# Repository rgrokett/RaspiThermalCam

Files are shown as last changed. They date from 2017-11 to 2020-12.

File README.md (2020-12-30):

# PiEyeR RaspiThermalCam
## Portable Raspberry Pi AMG8833 Grid-Eye IR Thermal Camera

version 0.8.2 - 2017-12-03

### Overview
The Adafruit AMG8833 IR Thermal Camera board can provide a “FLIR™”-like imaging camera at about 1/10th the price of previous IR Thermal imaging units.  Of course, the resolution and sensitivity are not as high as more advanced cameras, but hey, for $39 it’s a great deal.  

Note that IR Thermal Cameras are NOT the same as NOIR cameras. The former uses only the heat given off by the object being imaged, while the latter requires an infrared light source such as IR LEDs to illuminate the object. 

With this project, I took the excellent Adafruit tutorial [Raspberry Pi Thermal Camera](https://learn.adafruit.com/adafruit-amg8833-8x8-thermal-camera-sensor/raspberry-pi-thermal-camera) by Dean Miller and added extra functionality to the software and hardware.

The PiTFT display uses Adafruit's custom Linux Kernel. *(See below)* This project only needs the Jessie Lite-based PiTFT Resitive Image, as it does not use the GUI.

### New features:
- Safely shutdown/power up Raspberry
- Automatically runs software at powerup
- Battery Powered for portability
- Uses PiTFT GPIO buttons
- Sensitivity controls
- Screen snapshots
- Potential for future additions

**See Full Instructions in the [RaspiThermalCam.pdf](https://github.com/rgrokett/RaspiThermalCam/raw/master/RaspiThermalCam.pdf) document**

Zero Owners:  A Raspberry Pi Zero can be used instead of a Pi 3, sacrificing speed. See the subdirectory RaspiThermalCam/Zero for details.

### Requirements (summary)
**NOTE:** This project assumes the user has set up their Raspberry Pi using the Adafruit tutorial mentioned above, thus consists of:
1. [Raspberry Pi Thermal Camera](https://learn.adafruit.com/adafruit-amg8833-8x8-thermal-camera-sensor/raspberry-pi-thermal-camera) 
- Adafruit AMG8833 IR Thermal Camera Breakout [ID 3538](https://www.adafruit.com/product/3538)
2. It also specifically requires the Adafruit PiTFT Plus 2.8" 320x240 screen to be installed and running. 
- [Required PiTFT Kernal Install](https://learn.adafruit.com/adafruit-pitft-28-inch-resistive-touchscreen-display-raspberry-pi/easy-install)
- Download [Jessie Lite-based PiTFT image ](https://s3.amazonaws.com/adafruit-raspberry-pi/2016-10-18-pitft-28r-lite.zip)
- PiTFT Plus 2.8" TFT 320x240 Touch Screen [ID 2298](https://www.adafruit.com/product/2298)
3. Currently uses also:
- Raspberry Pi 3, 4GB or larger micro SD card
- 5V power supply, wiring, cables, etc.
4. It DOES NOT require the Cobbler as mentioned, but does need a cable to connect the camera. I suggest:
- Adafruit 40 Pin GPIO Cable [ID 1988](https://www.adafruit.com/product/1988)
- Adafruit 2X20 Pin IDC Box Header [ID 1993](https://www.adafruit.com/product/1993)

### Extras
- Faceplate and case for PiTFT and Raspberry Pi 3 [ID 2807](https://www.adafruit.com/product/2807)
- 5V external USB Battery (such as external cellphone rechargeable) with 2 amp output
- Box to hold battery, computer and camera 

### Installation
#### Pre Raspbian Buster:
You **MUST** have the Adafruit tutorial version installed and working before using this. This project just replaces the Adafruit thermalcam.py with a new python program. IT WILL NOT WORK OTHERWISE.

Also, it expects the assembled version of the Adafruit 2.8" 320x240 PiTFT Plus screen otherwise the screen layout will NOT ALIGN and the GPIO buttons will NOT FUNCTION as expected. The Raspbian GUI is NOT NEEDED, so uses their custom Jessie Lite. 

The camera should be facing forward, like a digital camera: LCD screen towards you and camera towards (hot) object. 

1. Log into the Raspberry Pi with SSH or keyboard (defaults to "pi/raspberry")
2. Download and install the enhanced thermal program:
```
git clone https://github.com/rgrokett/RaspiThermalCam.git
cd RaspiThermalCam
./install.sh
sudo reboot
```

#### Raspbian Buster Lite:
Wire up the thermal camera sensor and the PiTFT as outlined in the PDF in this repository. Make the necessary changes to raspi-config as outlined in the same PDF.

1. Log into the Raspberry Pi with SSH or keyboard (defaults to "pi/raspberry")
2. Download and install the enhanced thermal program:
```
git clone https://github.com/tenbergen/RaspiThermalCam.git
cd RaspiThermalCam
chmod +x ./buster-install.sh
./buster-install.sh
```
This will install the PiTFT and thermal sensor driver, if necessary. During PiTFT driver installation, select "4" for 2.8" capacitive PiTFT, then select "1" for 90 degree rotation, then select "no" for console on screen, then select "yes" for mirror HDMI output. Finally, select "no" to reboot.

The installer script will continue with the RaspiThermalCam installation. When complete, type:

```
sudo reboot
```

#### Overlay Kiosk:
In raspi-config, activate camera. Then, install using buster-install.sh.
Afterwards, type:
```
sudo pip3 install picamera
contab -e
```
and edit crontab to remove old script, and instead point to raspithermalcamoverlaykiosk.sh.

#### After Installation:
Once rebooted, you should see the new PiEyeR screen. See Troubleshooting if needed.  

The 4 buttons on the TFT screen have been re-mapped to GPIO functions as shown:

1. Safely Shutdown/Start up Raspberry (Does not remove 5V power, must be done usually via the 5V USB battery on/off switch)
2. Increase Sensitivity (while in Camera Mode)
3. Decrease Sensitivity (while in Camera Mode)
4. Start/Stop Camera Mode

### Snapshot
Due to a bug in the Python SDL library, the touch screen doesn’t currently work with PyGame software.  So I used the tslib and a small custom C program to detect screen touches.

Unfortunately, this broke in Raspbian Buster. Otherwise, to take a screenshot of a thermal image, just touch anywhere on the touch screen.  The screen will flash to let you know an image has been taken.
Images are saved to the /home/pi/snapshot subdirectory as  PNG files. These can be transferred to your PC using:

Mac/Linux:
$ scp pi@YOUR_IP_ADDRESS :/home/pi/snapshot/*.png .

Windows:
Use WinSCP program https://winscp.net/eng/download.php
Connect using SFTP with user name pi and Host name YOUR_IP_ADDRESS
Navigate to snapshot folder and select and download to your PC.

### 3D Print Case (early version)
The stl/ subdirectory contains 3D Printed front case parts for the camera. See the PDF document for details.

### Future 
- Switch to using Raspberry Pi Zero W for lower cost & power/smaller size
- Add new mode button features for middle buttons
- Get pygame Touch Screen working for PiTFT

### Troubleshooting

**I don't see any new screen, only the boot messages and login.** 

Did you run the ./install.sh script? 
Try running $ crontab -l and see if you see a @reboot line:
```
@reboot sudo python /home/pi/RaspiThermalCam/raspitherm.py >/dev/null 2>&1
``` 
You did set up your Pi Thermal Camera as detailed in the [Adafruit tutorial](https://learn.adafruit.com/adafruit-amg8833-8x8-thermal-camera-sensor/raspberry-pi-thermal-camera) 

**I get a python error message**
Most likely there is a missing python package. The last line of the Python error should say what is missing. Try Googling that message.
Else, leave an Issue here at Github.

**My screen is mangled up, but the buttons seem to work**
Are you using the PiTFT Plus 2.8" 320x240 screen?  

**My buttons don't work or are on the bottom not side of the PiTFT**
You have a different screen. If you have GPIO buttons on botton of TFT, you can try remapping them in the raspitherm.py program.

**The Touchscreen doesn't work**
Bugs in the SDL software used by pygame make for inconsistent operation of the touch screen. We have to wait for a better solution. This program doesn't use the touch, just buttons.

**My Camera screen is all BLUE or all RED**
Press the Sensitivity buttons (middle two) to increase/decrease sensitivity

**My Camera doesn't work**
Try manually running tools/thermal_cam.py program. This is the same program from Adafruit with no modifications.
You may need to kill the raspitherm.py program first by editing the crontab:
```
crontab -e
comment out the @reboot line
#@reboot ...
```
**What can I see with it?**
Find a cat. They glow hot!
So do water heaters!

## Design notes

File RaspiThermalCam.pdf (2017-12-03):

### PiEyeR – Enhanced Thermal Camera for Raspberry Pi

v. 2017-12-03 r.grokett

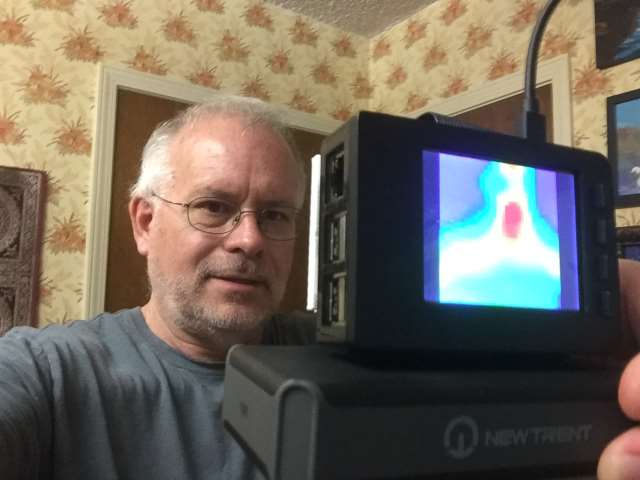
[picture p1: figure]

### Overview

The Adafruit AMG8833 IR Thermal Camera board can provide a “FLIR™”-like imaging camera at about 1/10th the price of previous IR Thermal imaging units. Of course, the resolution and sensitivity are not as high as more advanced cameras, but hey, for $39 it’s a great deal.

Note that IR Thermal Cameras are NOT the same as NOIR cameras. The former uses only the heat given off by the object being imaged, while the latter requires an infrared light source such as IR LEDs to illuminate the object.

With this project, I took the excellent Adafruit tutorial “Raspberry Pi Thermal Camera” by Dean Miller and added extra functionality to the software and hardware.

The PiTFT display uses Adafruit's custom Linux Kernel. (See below) This project only needs the Jessie Lite-based PiTFT Resistive Image, as it does not use the GUI.

New Features:

- Safely shutdown/power up Raspberry
- Automatically runs software at powerup
- Battery Powered for portability
- Uses PiTFT GPIO buttons
- Sensitivity controls
- Full screen thermal display
- Screen snapshots
- 3D printed case
- Potential for future additions

Hardware

- Raspberry Pi 3 (best) or Raspberry Pi W.
- Adafruit AMG8833 IR Thermal Camera Breakout https://www.adafruit.com/product/3538
- PiTFT Plus Assembled 320x240 2.8" TFT + Resistive Touchscreen https://www.adafruit.com/product/2298
- Faceplate and case for piTFT and RaspberryPi 3 https://www.adafruit.com/product/2807https://www.adafruit.com/product/2253
- Adafruit 40 Pin GPIO Cable https://www.adafruit.com/product/1988
- Adafruit 2X20 Pin IDC Box Header https://www.adafruit.com/product/1993
- 5V USB Battery (such as external cellphone rechargeable) 3000mah or larger
- 4GB or larger micro SD card for Raspberry
- Wire, connectors, etc. to match your connections
•

Software

- Custom Raspbian Jessie Lite for PiTFT (described below)
- Adafruit Libraries for PiTFT and AMG8833 (described below)
- SSH & Putty for Windows
- RaspiThermalCam from Github https://github.com/rgrokett/RaspiThermalCam

### I. Preliminary Setup

If you already have set up a Raspberry Pi with an Adafruit PiTFT Plus 320x240 screen and AMG8833 Thermal Camera module, then you can skip to the RaspiThermalCam Software in section II. below.

### Install PiTFT Display

Because the PiTFT Resistive Touch screen requires modifications to the Raspbian kernel, it is STRONGLY suggested to start fresh with the custom pre-built Raspbian Jessie image from Adafruit. This already contains all the necessary drivers for the PiTFT screen.

Note that this is going to be a “headless” installation, thus will not be using the Raspbian GUI. You will be using the linux command-line to configure and program the Raspberry. The easiest way to access is to set up SSH and WiFi or Ethernet connectivity and use a remote terminal program like Putty.

The below instructions are taken from Adafruit PiTFT tutorial at the URL below. NOTE that if you have difficulties or want to see the full instructions please visit this site: https://learn.adafruit.com/adafruit-pitft-28-inch-resistive-touchscreen-display-raspberry-pi/easy-install

PiTFT Installation Steps

1) Download the piTFT Raspian Jessie Lite from Adafruit to a PC: https://s3.amazonaws.com/adafruit-raspberry-pi/2016-10-18-pitft-28r-lite.zip
2) Install this image on a 4GB or larger SD card. If you need help here, check out instructions at https://www.raspberrypi.org/documentation/installation/installing-images/
3) Insert the micro SD card into the Pi.
4) Before installing the piTFT onto the Pi, plug the 40 pin GPIO Cable into the back of the piTFT. BE SURE to position the GRAY line mark on the cable on PIN 1 of the piTFT male connector. Note that there are two connectors on the PiTFT module; a female connector that plugs into the Raspberry Pi, and a male connector that this cable connects to.

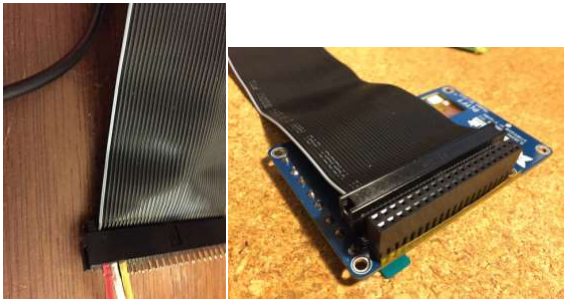
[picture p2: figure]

This will be used to connect the Thermal Camera module later.
(Actually, you only need 4 wires to connect the camera, but due to dimensions, it’s easiest to just use this ready-made cable as is.)
5) Now plug in the PiTFT onto the Raspberry Pi itself. Again, look at the photos to see which way it should go. (gray to pin 1)
6) Verify that the GRAY line mark on the GPIO cable is positioned as shown.

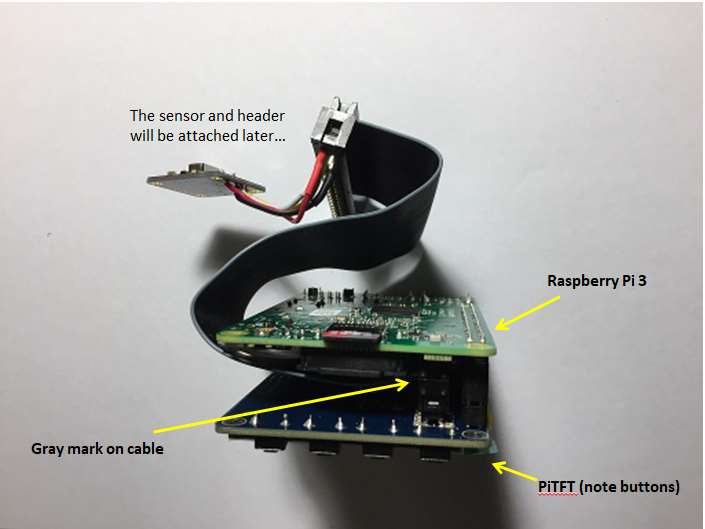
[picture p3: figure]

Now you are ready to test the PiTFT and Raspberry Pi. (The IR Image Sensor will be installed later).

7) Connect a USB keyboard into one of the Raspi ports. (No mouse is needed). This will make it easier to initially log in and find the IP address that is assigned. Otherwise, you’ll need to check your router for the IP assignment.
8) For network connectivity, the easiest is just plug in an Ethernet cable, though you can set up WiFi manually via wpa_supplicant.conf if you prefer.

Note that once the IR camera is completed, you won’t need networking, so wifi isn’t needed.

9) Connect 5V power and let your pi boot. If all goes well, after a few seconds, the PiTFT screen should show boot messages and then a login prompt.

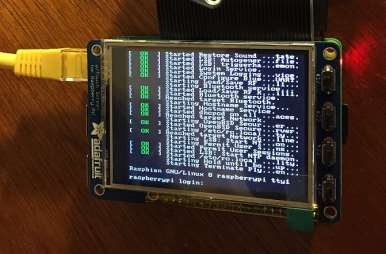
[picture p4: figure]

If you do not see any display, verify your connection (bent pins?), power supply and SD card are all good. Also see the Adafruit FAQ: https://learn.adafruit.com/adafruit-pitft-28-inch-resistive-touchscreen-display-raspberrypi/help-faq (https://learn.adafruit.com/adafruit-pitft-28-inch-resistive-touchscreen-display-raspberry-pi/help-faq)

10) Login & passwd are the default “pi” “raspberry”.
11) Locate the IP address using $ ifconfig –a
Now you can remotely log in using SSH Putty using pi@YOUR_IP_ADDRESS
You can unplug the keyboard once you successfully ssh in.
(Remote access is only needed just to make it easier to complete the setup, not for normal use.)
12) Update your package manager:

sudo apt-get update

IMPORTANT NOTE! Do NOT run “apt-get upgrade” or “rpi-update”!
This would overwrite the custom Adafruit kernel needed to run the PiTFT. If you do, probably easiest is to just start over. Or consult the Adafruit FAQ above.
This Pi will not be accessible from the Internet, so security patches aren’t as critical.
(If paranoid, just turn off WiFi and only use Ethernet cable.)

### AMG8833 Image Sensor Setup

The following is excerpted instructions from Adafruit’s Thermal Camera tutorial. Feel free to examine it for more details:
https://learn.adafruit.com/adafruit-amg8833-8x8-thermal-camera-sensor/raspberry-pi-thermal-camera
1) Run the following to install the Raspberry Library and Adafruit GPIO

sudo apt-get install -y build-essential python-pip python-dev python-smbus git git clone https://github.com/adafruit/Adafruit_Python_GPIO.git

cd Adafruit_Python_GPIO

sudo python setup.py install

sudo apt-get install -y python-scipy python-pygame

sudo pip install colour Adafruit_AMG88xx

This installs all the packages and libraries needed to drive the IR Image Sensor.

2) Enable the I2C Interface for the IP camera:

sudo raspi-config

Navigate to 9 Advanced Options and select A7 I2C then select Finish

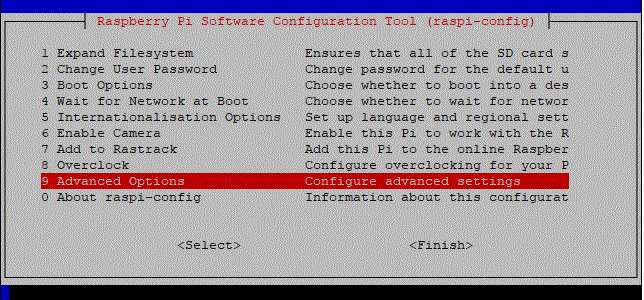
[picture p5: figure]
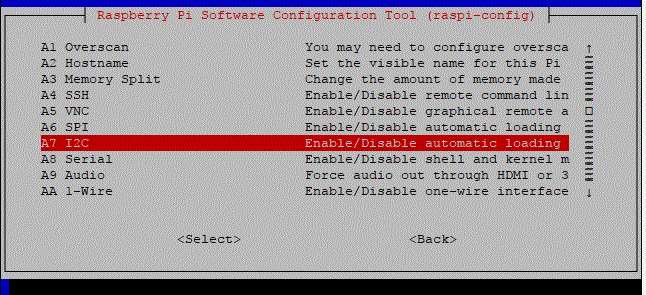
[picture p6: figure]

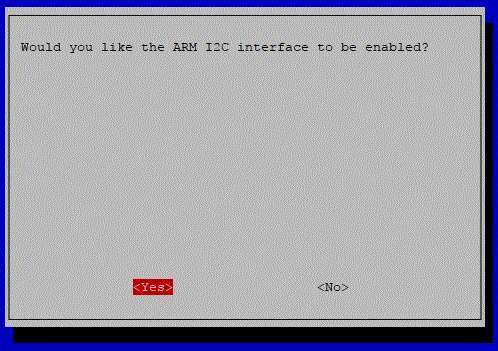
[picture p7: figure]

3) Shutdown Raspi and unplug the power cable (and Ethernet cable, if connected):

sudo shutdown -h now

Wiring the IR Module

You will be connecting only 4 pins of the AMG8833 IP to the 2x20 IDC Box Header and plugging this into the 40 wire GPIO cable.

For the most reliable wiring connectivity, I suggest soldering 4 short wires to the pins on the IR module and to the 2x20 Header. Use a needle point soldering iron and magnifier for best results. Use heat shrink tubing to protect the connections.

Be sure to note the direction positioning of the Header. There is a cutout key and a tiny arrow marking pin 1. (This is inverted from GPIO diagrams due to the cable/header arrangement)

Also note the direction that the IR camera should be pointing away from the Raspi.

IR MODULE | RASPBERRY PI (2x20 Box Header) | DESC
VIN | Pin 1 | 3.3V
GND | Pin 6 | Ground
SDA | Pin 3 | SDA
SCL | Pin 5 | SCL

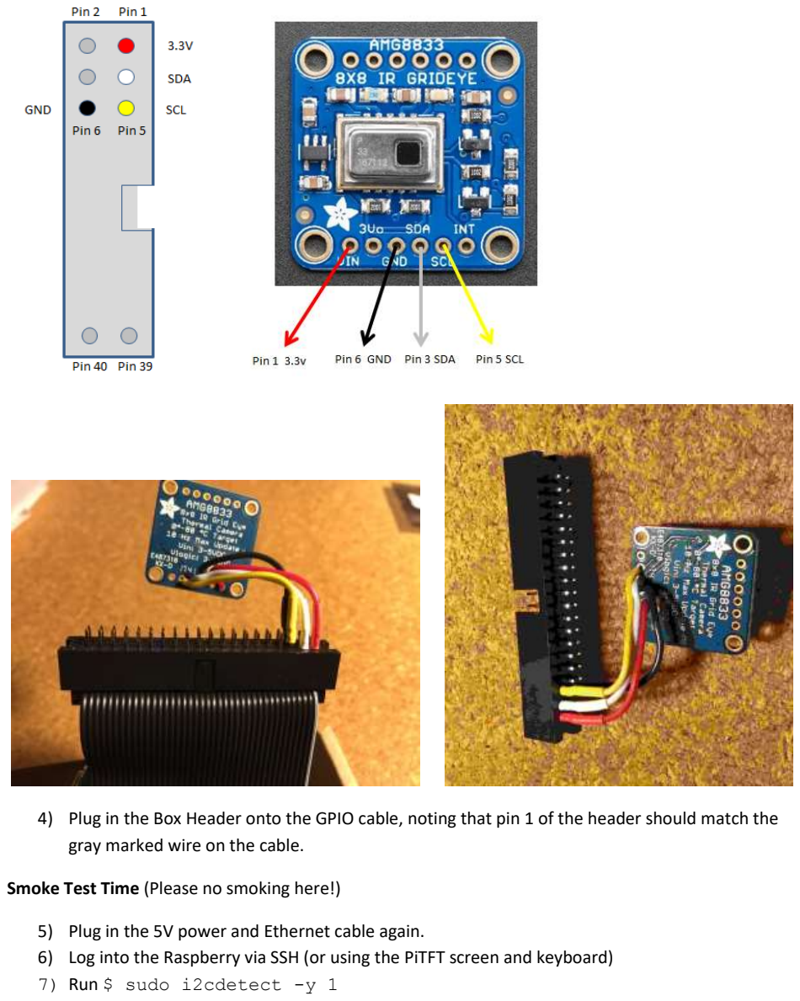
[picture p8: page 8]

4) Plug in the Box Header onto the GPIO cable, noting that pin 1 of the header should match the gray marked wire on the cable.

Smoke Test Time (Please no smoking here!)

5) Plug in the 5V power and Ethernet cable again.
6) Log into the Raspberry via SSH (or using the PiTFT screen and keyboard)
7) Run $ sudo i2cdetect -y 1

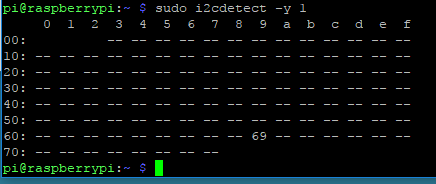
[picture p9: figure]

You should see the “69” entry. If not, did you enable the I2C interface via raspi-config? Also verify wiring!

8) Run the Example code!

cd ~/

git clone https://github.com/adafruit/Adafruit_AMG88xx_python.git

cd Adafruit_AMG88xx_python/examples

sudo python thermal_cam.py

If all is well, you should see a heat map image when you wave your hand or stand in front of the camera!

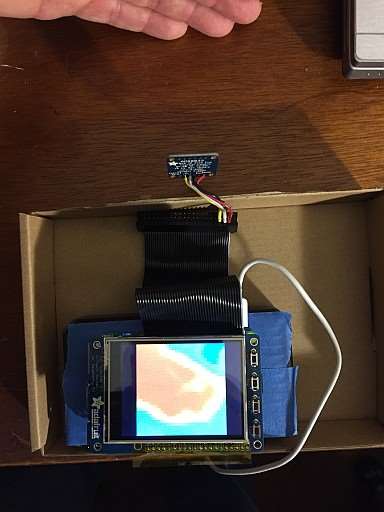
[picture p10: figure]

Once completed, the camera should be facing forward, like a digital camera: The LCD screen towards you and camera towards (hot) object.

### II. RaspiThermalCam Software

Now that you have a working Raspberry Pi Thermal Camera, the next step is to add extra software functionality and package everything into a more portable unit.

Before beginning, I suggest changing the password and setting the timezone.

$ sudo raspi-config

Select “Change User Password” and change as directed.
Then select “Internationalization Options” -> “Change TimeZone” and find a country/city in your timezone. Type first letter A-Z or page up/down to skip cities quickly.

Now to install the PiEyeR RaspiThermal software:

1) Install GIT, if needed:
| $ sudo apt-get install git
2) Download the RaspiThermalCam software
| $ cd ~/ $ git clone https://github.com/rgrokett/RaspiThermalCam.git
3) Run the Installation script
| $ cd RaspiThermalCam $ ./install.sh $ sudo reboot

Once rebooted, you should see the new PiEyeR screen.

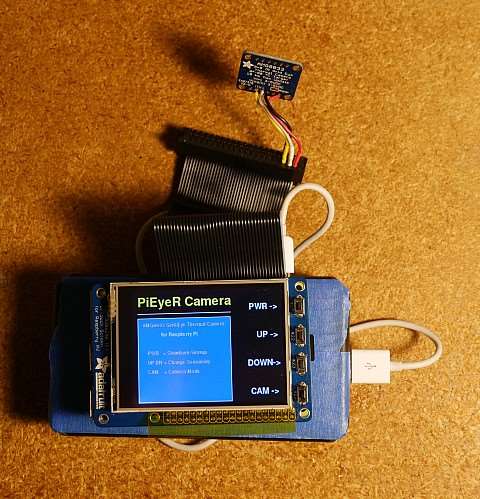
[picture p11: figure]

See Troubleshooting if needed.

The 4 buttons on the TFT screen have been re-mapped to GPIO functions as shown:

Button | GPIO | Desc
1 | 17 | Safely Shutdown/Start up Raspberry (Does not remove 5V power, must be done usually via the 5V USB battery on/off switch)
2 | 22 | Increase Sensitivity (while in Camera Mode)
3 | 23 | Decrease Sensitivity (while in Camera Mode)
4 | 27 | Start/Stop Camera Mode
(If needed, you can remap the buttons to your TFT screen’s GPIO pins by editing the "raspitherm.py" program.)

### Screenshots

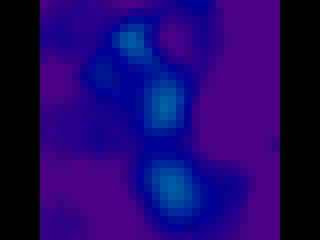
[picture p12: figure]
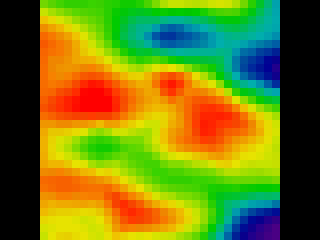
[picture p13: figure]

Due to a bug in the Python SDL library, the touch screen doesn’t currently work correctly with PyGame software. So I used the tslib and a small custom C program to detect screen touches.

To take a screenshot of a thermal image, just touch anywhere on the touch screen. The screen will flash to let you know an image has been taken.

Images are saved to the /home/pi/snapshot subdirectory as PNG files. These can be transferred to your PC using:

Mac/Linux:

$ scp –p pi@YOUR_IP_ADDRESS :/home/pi/snapshot/*.png .

Windows:
Use WinSCP program https://winscp.net/eng/download.php
Connect using SFTP with user name pi and Host name YOUR_IP_ADDRESS Navigate to snapshot folder and select and download to your PC.

### Packaging Construction

If you are going to use this outside, you should ruggedize it by soldering all wiring (or verify strong connections) and building a case. I used a simple 3D printed case I designed.

This also will use the Adafruit front faceplate, buttons and case for the Raspberry.

You will also need a large 5V USB battery to power the Pi 3, which I just attached separately using Velcro.

### 3D Printed Case

The RaspiThermalCam/stl/ subdirectory contains STL files for 3D printing a simple front-end case for the thermal sensor. It’s currently not very fancy and expects the Raspberry Pi 3 and PiTFT screen to use the Adafruit faceplate and case.

1. Print out the three pieces; body, front plate, back bracket.
2. Clip out the support tips along one edge of the wide end of the Body. This is where the ribbon cable will go thru.
3. Slip the Body over the AMG8833 camera module and cables, wide end towards the Raspberry Pi case.
4. Pull the camera module up through the front (narrower) end of the Body.
5. Place the camera through the hole in the front plate. Note that the ridge on the front plate faces OUTWARDS, thus helps protect the imager.
6. Place the bracket behind the camera module circuit board. The camera should be just lightly held in place by the bracket
7. Use two small screws/nuts to attach the bracket to the front plate with the camera sandwiched between.
8. Currently, I just glued the front plate to the Body. The camera can still be removed from the case by removing the screws and back bracket.
9. I also just attached the wide end of the Body to the Raspberry Pi case using hot melt glue, which can be cut or melted to open it back up.

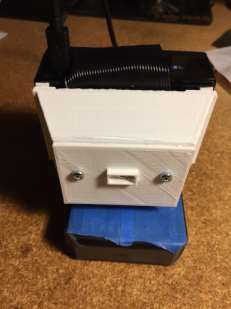
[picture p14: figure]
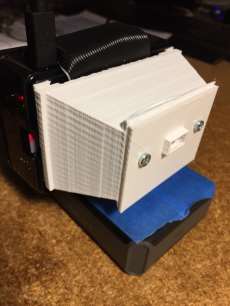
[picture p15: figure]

NOTE that you cannot cover the front lens of the AMG8833 as most glass or clear plastics will absorb the far-infrared, thus be opaque to the camera.

Since my next version of the PiEyeR is to try to replace the Raspberry Pi 3 with a Zero W, all of the case designs will change.

Feel free to design a better case and let me know!!

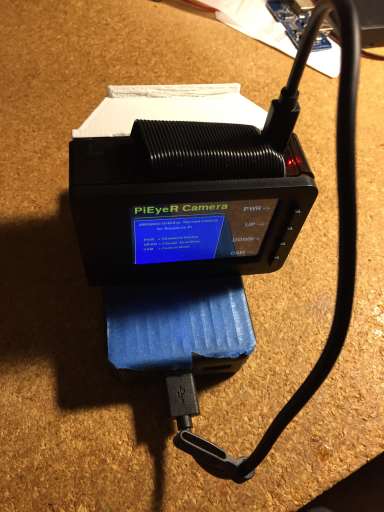
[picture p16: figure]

### Future Features

- Switch to using Raspberry Pi Zero W for lower cost & power/smaller size
- Add new mode button features for middle buttons
- Get pygame Touch Screen working for PiTFT

### Troubleshooting

**I don't see any new screen, only the boot messages and login.**

Did you run the ./install.sh script?
Try running $ crontab -l and see if you see a @reboot line:

@reboot sudo python /home/pi/RaspiThermalCam/raspitherm.py >/dev/null 2>&1

You did set up your Pi Thermal Camera as detailed in the Adafruit tutorial? (https://learn.adafruit.com/adafruit-amg8833-8x8-thermal-camera-sensor/raspberry-pi-thermal-camera)

**I get a python error message**

Most likely there is a missing python package. The last line of the Python error should say what is missing. Try Googling that message.
Else, leave an Issue at Github.

**My screen is mangled up, but the buttons seem to work**
Are you using the PiTFT Plus 2.8" 320x240 screen?

**My buttons don't work or are on the bottom not side of the PiTFT**
You have a different screen. If you have GPIO buttons on botton of TFT, you can try remapping them in the raspitherm.py program.

**The Touchscreen doesn't work**
Bugs in the SDL software used by pygame make for inconsistent operation of the touch screen. We have to wait for a better solution. This program doesn't use the touch, just buttons.

**My Camera screen is all BLUE or all RED**
Press the Sensitivity buttons (middle two) to increase/decrease sensitivity

**My Camera doesn't work**
Try manually running tools/thermal_cam.py program. This is the same program from Adafruit with no modifications.
You may need to kill the raspitherm.py program first by editing the crontab:

crontab -e
comment out the @reboot line
#@reboot ...

**What can I see with it?**

Find a cat. They glow hot! So do water heaters!

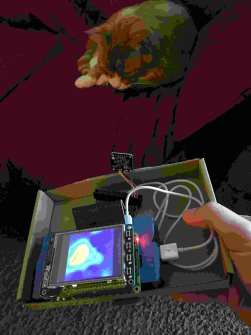
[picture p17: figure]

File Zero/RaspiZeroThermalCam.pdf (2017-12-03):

### PiEyeR – Enhanced Thermal Camera for Raspi Zero

### Raspberry Pi Zero Version

v. 2017-12-03 r.grokett


### Overview

The Adafruit AMG8833 IR Thermal Camera board can provide a “FLIR™”-like imaging camera at about 1/10th the price of previous IR Thermal imaging units. Of course, the resolution and sensitivity are not as high as more advanced cameras, but hey, for $39 it’s a great deal.

Note that IR Thermal Cameras are NOT the same as NOIR cameras. The former uses only the heat given off by the object being imaged, while the latter requires an infrared light source such as IR LEDs to illuminate the object.

With this project, I took the excellent Adafruit tutorial “Raspberry Pi Thermal Camera” by Dean Miller and added extra functionality to the software and hardware.

This version is for the Raspberry Pi Zero

The PiTFT display uses Adafruit's custom Linux Kernel. (See below) This project only needs the Jessie Lite-based PiTFT Resistive Image, as it does not use the GUI.

This custom Kernel does not currently support WiFi, so you will need to use a USB Ethernet adapter during setup. (Networking is not needed for normal operation) See parts list below

New Features:

- Safely shutdown/power up Raspberry
- Automatically runs software at powerup
- Battery Powered for portability
- Uses PiTFT GPIO buttons
- Sensitivity controls
- Full screen thermal display
- Screen snapshots
- 3D printed case
- Potential for future additions

Hardware

- Raspberry Pi Zero
- Adafruit AMG8833 IR Thermal Camera Breakout https://www.adafruit.com/product/3538
- PiTFT Plus Assembled 320x240 2.8" TFT + Resistive Touchscreen https://www.adafruit.com/product/2298
- Faceplate and case for piTFT and RaspberryPi https://www.adafruit.com/product/2807https://www.adafruit.com/product/2253
- Adafruit 40 pin header for Raspberry Pi Zero
- Adafruit 40 Pin GPIO Cable https://www.adafruit.com/product/1988
- Adafruit 2X20 Pin IDC Box Header https://www.adafruit.com/product/1993
- Adafruit micro Ethernet and USB hub https://www.adafruit.com/product/2992
- 5V USB Battery (such as external cellphone rechargeable) 2000mah or larger
- 4GB or larger micro SD card for Raspberry
- Wire, connectors, etc. to match your connections

Software

- Custom Raspbian Jessie Lite for PiTFT (described below)
- Adafruit Libraries for PiTFT and AMG8833 (described below)
- SSH & Putty for Windows
- RaspiThermalCam from Github https://github.com/rgrokett/RaspiThermalCam

### I. Preliminary Setup

### Solder a Male Header to Zero

1. Solder a 40 pin Male header to the Raspberry Pi Zero, top side (component side) of board.

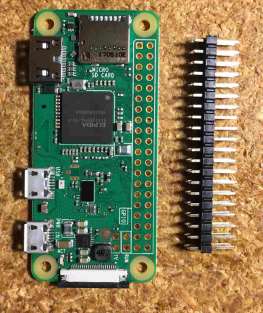
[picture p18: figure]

### Install PiTFT Display

Because the PiTFT Resistive Touch screen requires modifications to the Raspbian kernel, it is STRONGLY suggested to start fresh with the custom pre-built Raspbian Jessie image from Adafruit. This already contains all the necessary drivers for the PiTFT screen.

Note that this is going to be a “headless” installation, thus will not be using the Raspbian GUI. You will be using the linux command-line to configure and program the Raspberry. The easiest way to access is to set up SSH and Ethernet connectivity and use a remote terminal program like Putty.

The below instructions are taken from Adafruit PiTFT tutorial at the URL below. NOTE that if you have difficulties or want to see the full instructions please visit this site: https://learn.adafruit.com/adafruit-pitft-28-inch-resistive-touchscreen-display-raspberry-pi/easy-install

PiTFT Installation Steps

1) Download the piTFT Raspian Jessie Lite from Adafruit to a PC: https://s3.amazonaws.com/adafruit-raspberry-pi/2016-10-18-pitft-28r-lite.zip
2) Install this image on a 4GB or larger SD card. If you need help here, check out instructions at https://www.raspberrypi.org/documentation/installation/installing-images/
3) Insert the micro SD card into the Pi.
4) Before installing the piTFT onto the Pi, plug the 40 pin GPIO Cable into the back of the piTFT. BE SURE to position the GRAY line mark on the cable on PIN 1 of the piTFT male connector. Note that there are two connectors on the PiTFT module; a female connector that plugs into the Raspberry Pi, and a male connector that this cable connects to.

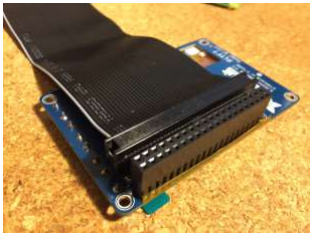
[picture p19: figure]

This will be used to connect the Thermal Camera module later.
(Actually, you only need 4 wires to connect the camera, but due to dimensions, it’s easiest to just use this ready-made cable as is.)
5) Now plug in the Pi Zero onto the PiTFT itself. Again, look at the photos to see which way it should go. (gray to pin 1)
6) Verify that the GRAY line mark on the GPIO cable is positioned as shown.

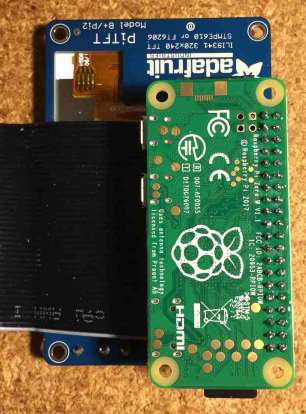
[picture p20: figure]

Now you are ready to test the PiTFT and Raspberry Pi. (The IR Image Sensor will be installed later).

7) Plug the Ethernet/USB hub into the second USB port (not the usb power port).
8) Connect a USB keyboard into one of the Raspi ports. (No mouse is needed). This will make it easier to initially log in and find the IP address that is assigned. Otherwise, you’ll need to check your router for the IP assignment.
9) For network connectivity, plug an Ethernet cable into the hub.
NOTE that WiFi does not work (currently) with the custom Jessie kernel.
Once the IR camera is completed, you won’t need networking, so wifi isn’t needed.
The keyboard and Ethernet/USB hub also won’t be needed after your camera is completed.
10) Connect 5V power and let your pi boot. If all goes well, after a 20-30 seconds, the PiTFT screen should show boot messages and then a login prompt.


If you do not see any display, or blank white, verify your connection (bent pins?), power supply and SD card are all good. Also see the Adafruit FAQ: https://learn.adafruit.com/adafruit-pitft-28-inch-resistive-touchscreen-display-raspberrypi/help-faq (https://learn.adafruit.com/adafruit-pitft-28-inch-resistive-touchscreen-display-raspberry-pi/help-faq)

11) Login & passwd are the default “pi” “raspberry”.
12) Locate the IP address using $ ifconfig –a
Now you can remotely log in using SSH Putty using pi@YOUR_IP_ADDRESS
You can unplug the keyboard once you successfully ssh in.
(Remote access is only needed just to make it easier to complete the setup, not for normal use.)
13) Update your package manager:

sudo apt-get update

IMPORTANT NOTE! Do NOT run “apt-get upgrade” or “rpi-update”!

This would overwrite the custom Adafruit kernel needed to run the PiTFT. If you do, probably easiest is to just start over. Or consult the Adafruit FAQ above.
This Pi will not be accessible from the Internet, so security patches aren’t as critical.

### AMG8833 Image Sensor Setup

The following is excerpted instructions from Adafruit’s Thermal Camera tutorial. Feel free to examine it for more details:
https://learn.adafruit.com/adafruit-amg8833-8x8-thermal-camera-sensor/raspberry-pi-thermal-camera
1) Run the following to install the Raspberry Library and Adafruit GPIO

sudo apt-get update

sudo apt-get install -y build-essential python-pip python-dev python-smbus git

git clone https://github.com/adafruit/Adafruit_Python_GPIO.git

cd Adafruit_Python_GPIO

sudo python setup.py install

sudo apt-get install -y python-scipy python-pygame

sudo pip install colour Adafruit_AMG88xx

This installs all the packages and libraries needed to drive the IR Image Sensor.

2) Enable the I2C Interface for the IP camera:

sudo raspi-config

Navigate to 9 Advanced Options and select A7 I2C then select Finish



3) Shutdown Raspi and unplug the power cable (and Ethernet cable, if connected):

sudo shutdown -h now

Wiring the IR Module

You will be connecting only 4 pins of the AMG8833 IP to the 2x20 IDC Box Header and plugging this into the 40 wire GPIO cable.

For the most reliable wiring connectivity, I suggest soldering 4 short wires to the pins on the IR module and to the 2x20 Header. Use a needle point soldering iron and magnifier for best results. Use heat shrink tubing to protect the connections.

Be sure to note the direction positioning of the Header. There is a cutout key and a tiny arrow marking pin 1. (This is inverted from GPIO diagrams due to the cable/header arrangement)

Also note the direction that the IR camera should be pointing away from the Raspi.

IR MODULE | RASPBERRY PI (2x20 Box Header) | DESC
VIN | Pin 1 | 3.3V
GND | Pin 6 | Ground
SDA | Pin 3 | SDA
SCL | Pin 5 | SCL

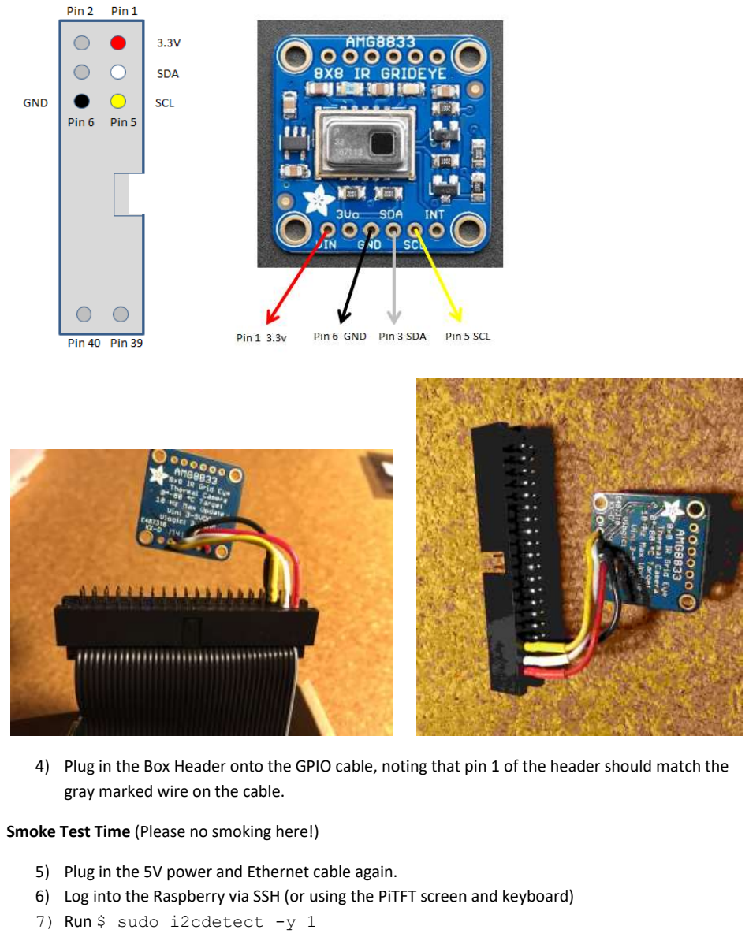
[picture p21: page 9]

4) Plug in the Box Header onto the GPIO cable, noting that pin 1 of the header should match the gray marked wire on the cable.

Smoke Test Time (Please no smoking here!)

5) Plug in the 5V power and Ethernet cable again.
6) Log into the Raspberry via SSH (or using the PiTFT screen and keyboard)
7) Run $ sudo i2cdetect -y 1


You should see the “69” entry. If not, did you enable the I2C interface via raspi-config? Also verify wiring!

8) Run the Example code!

cd ~/

git clone https://github.com/adafruit/Adafruit_AMG88xx_python.git

cd Adafruit_AMG88xx_python/examples

sudo python thermal_cam.py

If all is well, you should see a heat map image when you wave your hand or stand in front of the camera!


Once completed, the camera should be facing forward, like a digital camera: The LCD screen towards you and camera towards (hot) object.

### II. RaspiThermalCam Software

Now that you have a working Raspberry Pi Thermal Camera, the next step is to add extra software functionality and package everything into a more portable unit.

For network connectivity, plug an Ethernet cable into the hub. Access using SSH via Putty.
NOTE that WiFi does not work (currently) with the custom Jessie kernel.

Before beginning, I suggest changing the password and setting the timezone.

$ sudo raspi-config

Select “Change User Password” and change as directed.
Then select “Internationalization Options” -> “Change TimeZone” and find a country/city in your timezone. Type first letter A-Z or page up/down to skip cities quickly.

Now to install the PiEyeR RaspiThermal software:

1) Install GIT, if needed:

$ sudo apt-get install git

2) Download the RaspiThermalCam software
$ cd ~/
$ git clone https://github.com/rgrokett/RaspiThermalCam.git
3) Run the Installation script
$ cd RaspiThermalCam
$ ./install.sh
$ sudo reboot

Once rebooted, you should see the new PiEyeR screen.


See Troubleshooting if needed.

The 4 buttons on the TFT screen have been re-mapped to GPIO functions as shown:

Button | GPIO | Desc
1 | 17 | Safely Shutdown/Start up Raspberry (Does not remove 5V power, must be done usually via the 5V USB battery on/off switch)
2 | 22 | Increase Sensitivity (while in Camera Mode)
3 | 23 | Decrease Sensitivity (while in Camera Mode)
4 | 27 | Start/Stop Camera Mode
(If needed, you can remap the buttons to your TFT screen’s GPIO pins by editing the "raspitherm.py" program.)

### Screenshots


Due to a bug in the Python SDL library, the touch screen doesn’t currently work correctly with PyGame software. So I used the tslib and a small custom C program to detect screen touches.

To take a screenshot of a thermal image, just touch anywhere on the touch screen. The screen will flash to let you know an image has been taken.

Images are saved to the /home/pi/snapshot subdirectory as PNG files. These can be transferred to your PC using:

Mac/Linux:

$ scp –p pi@YOUR_IP_ADDRESS :/home/pi/snapshot/*.png .

Windows:
Use WinSCP program https://winscp.net/eng/download.php
Connect using SFTP with user name pi and Host name YOUR_IP_ADDRESS Navigate to snapshot folder and select and download to your PC.

### Packaging Construction

If you are going to use this outside, you should ruggedize it by soldering all wiring (or verify strong connections) and building a case. I used a simple 3D printed case I designed.

This also will use the Adafruit front faceplate, buttons and case for the Raspberry.

You will also need a large 5V USB battery to power the Pi 3, which I just attached separately using Velcro.

### 3D Printed Case

(FUTURE)

NOTE that you cannot cover the front lens of the AMG8833 as most glass or clear plastics will absorb the far-infrared, thus be opaque to the camera.

Feel free to design a better case and let me know!!

### Future Features

- 3D Printed Case for Raspi Zero
- Add new mode button features for middle buttons
- Get pygame Touch Screen working for PiTFT

### Troubleshooting

**I don't see any new screen, only the boot messages and login.**

Did you run the ./install.sh script?
Try running $ crontab -l and see if you see a @reboot line:

@reboot sudo python /home/pi/RaspiThermalCam/raspitherm.py >/dev/null 2>&1

You did set up your Pi Thermal Camera as detailed in the Adafruit tutorial? (https://learn.adafruit.com/adafruit-amg8833-8x8-thermal-camera-sensor/raspberry-pi-thermal-camera)

**WIFI does not work**

The custom Jessie kernel used to support the PiTFT touch screen doesn’t have the WiFi drivers yet. This will be a future project, but the camera doesn’t really need networking much.

**I get a python error message**

Most likely there is a missing python package. The last line of the Python error should say what is missing. Try Googling that message.
Else, leave an Issue at Github.

**My screen is mangled up, but the buttons seem to work**
Are you using the PiTFT Plus 2.8" 320x240 screen?

**My buttons don't work or are on the bottom not side of the PiTFT**
You have a different screen. If you have GPIO buttons on botton of TFT, you can try remapping them in the raspitherm.py program.

**The Touchscreen doesn't work**
Bugs in the SDL software used by pygame make for inconsistent operation of the touch screen. We have to wait for a better solution. This program doesn't use the touch, just buttons.

**My Camera screen is all BLUE or all RED**
Press the Sensitivity buttons (middle two) to increase/decrease sensitivity

**My Camera doesn't work**
Try manually running tools/thermal_cam.py program. This is the same program from Adafruit with no modifications.
You may need to kill the raspitherm.py program first by editing the crontab:

crontab -e
comment out the @reboot line
#@reboot ...

**What can I see with it?** Find a cat. They glow hot! So do water heaters!


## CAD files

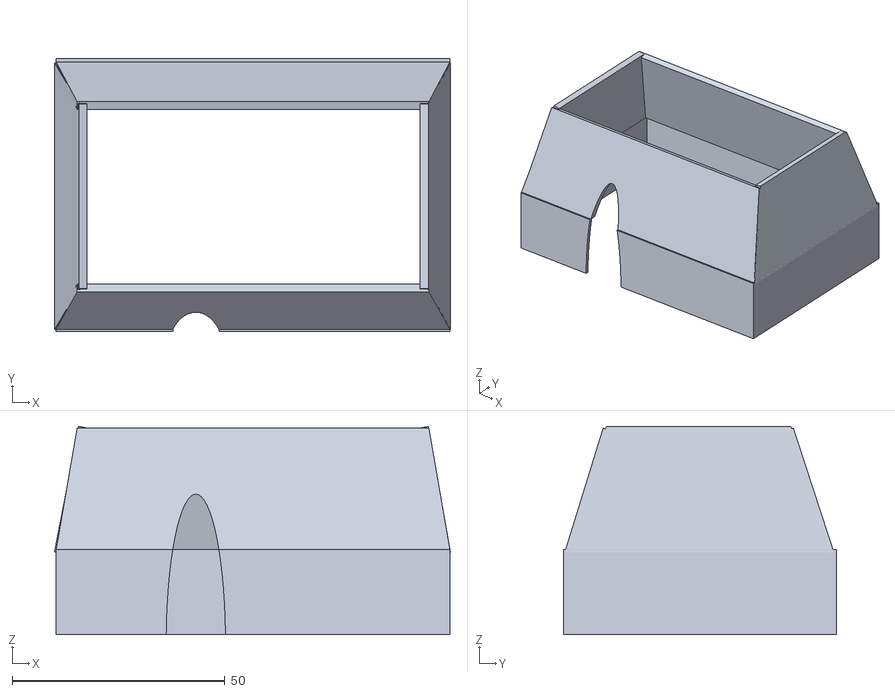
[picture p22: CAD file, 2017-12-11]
Zero/stl/PiEyeR Zero Back.stl
93.0 x 64.0 x 48.9

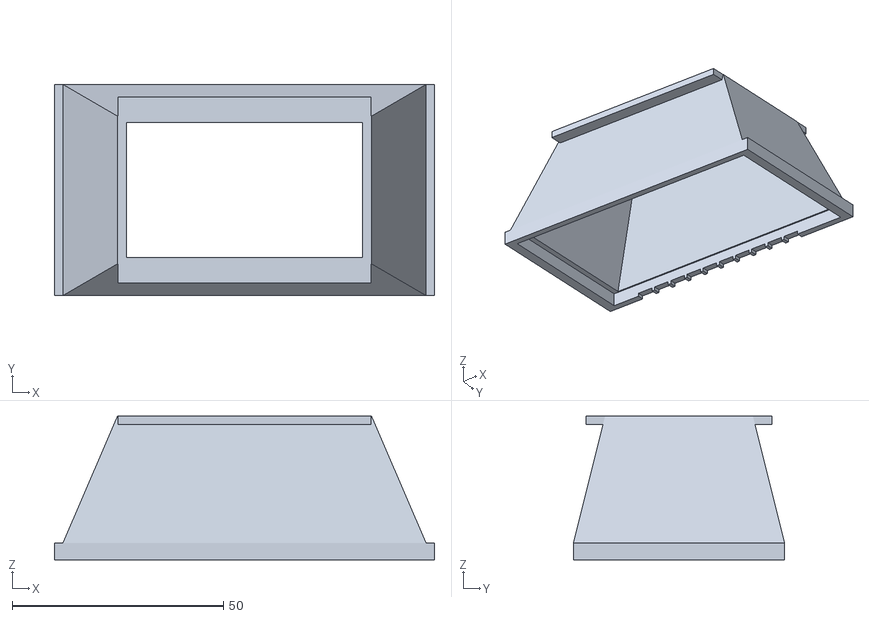
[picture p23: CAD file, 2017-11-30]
Zero/stl/PiEyeR Body.stl
90.0 x 50.0 x 34.0

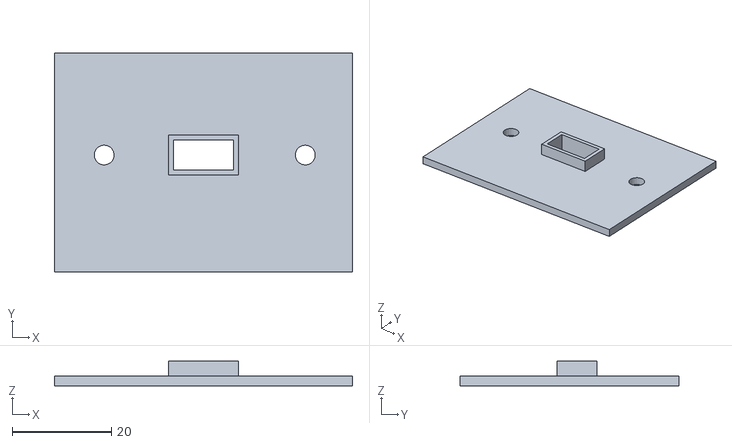
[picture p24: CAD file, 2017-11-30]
Zero/stl/PiEyeR Front.stl
60.0 x 44.0 x 5.00

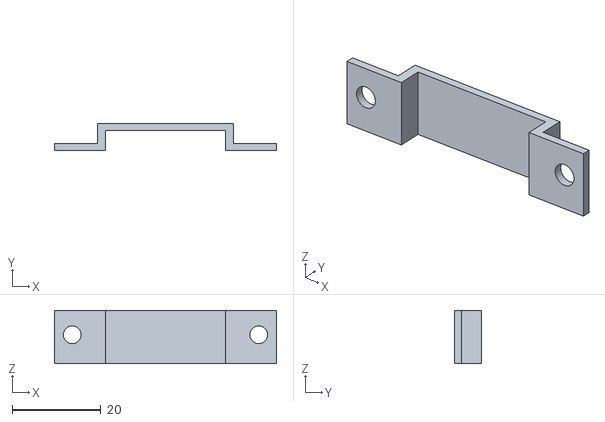
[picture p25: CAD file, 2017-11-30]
Zero/stl/PiEyeR CamBackPlate.stl
50.0 x 6.00 x 12.0

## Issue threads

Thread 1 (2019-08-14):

Locks up after 3 seconds in camera mode, waits for UP/DOWN button press

Derpalupagus, 2019-08-14:
In Camera mode, image runs for 3 seconds and then freezes.  Unfreezes after UP or DOWN button press and then freezes 3 seconds later.  Tried the latest code and verified no tabs, still freezes up predictably.

Derpalupagus, 2019-08-15:
Found it - pygame.display.update() on Line 220 is inside the if(showBtns = 25) loop, so once showBtns = 25, the display will not update.  Solution is to outdent the pygame.display.update() in Line 220 to outside of the if(showBtns = 25) loop.  Correct structure follows:

       # Add buttons (show for X seconds)
        if (showBtns < 25):
            fnt = pygame.font.Font(None, 15)
            mode_buttons = {'PWR ->':(280,40), '   UP ->':(280,100), 'DOWN->':(280,160), 'MODE->':(280,220)}
            for k,v in mode_buttons.items():
                text_surface = fnt.render('%s'%k, True, GRAY)
                rect = text_surface.get_rect(center=v)
                lcd.blit(text_surface, rect)
                showBtns = showBtns + 1
                # Add Data to screen
                fnt = pygame.font.Font(None, 15)
                cur_date = datetime.datetime.now().strftime('%a  %d  %b %H : %M : %S %Z %Y')
                text_surface = fnt.render(cur_date, True, GRAY)
                lcd.blit(text_surface, (10,220))
                text = "Min  = {0:.0f} C".format(min(pixels_d))
                text_surface = fnt.render(text, True, GRAY)
                lcd.blit(text_surface, (10,20))
                text = "Max = {0:.0f} C".format(max(pixels_d))
                text_surface = fnt.render(text, True, GRAY)
                lcd.blit(text_surface, (10,30))
    pygame.display.update()
        # GPIO Button Press

rgrokett, 2019-08-15:
Updated raspitherm.py.   I also noticed that the touch() call on line 238 wasn't outdented properly either.  It should line up with the If statements, but note that the touch library for pygame have unfixed issues in low level C library for some touch screens (inc. the one from Adafruit). So you may have to comment out line 238 if touch doesn't work.    There are touch related test programs in tools/ directory. I haven't checked to see if this was fixed in Raspbian Buster yet.

Derpalupagus, 2019-08-15:
The snapshot touch() funciton works using tslib, or least it does for me.  I just hadn't gotten that far into the project yet.  Everything else looks like it's working fine now.

Closed 2019-08-15.

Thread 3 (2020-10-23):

Buttons not working? Or i might be dumb.

pyobox, 2020-10-23:
@rgrokett I downloaded raspitherm.py, got all the dependecies.  When I run the module I get thd menue svreen
PWR =Shutdown Startup
UP/DN =Change Sensitivity
CAM =Camera Mode
Touch Screen for Snapshot.

I made no changes to the code.  My question is how do I interact with the menue in order to initiate Cam or camera mode
I'm not using touch screen, mouse clicks and keyboard presses aren't doing anything

Closed 2020-10-24.

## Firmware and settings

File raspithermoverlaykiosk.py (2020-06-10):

#!/usr/bin/python
# 
# PiEyeR - Raspberry Pi Thermal Camera 
#
# Enhanced version of Adafruit Raspberry Pi Thermal Camera
# Based on Adafruit AMG8833 Grid-Eye module and PiTFT 2.8" screen
#
# Normally run by pi crontab at bootup
# Turn off by commenting out @reboot... using $ crontab -e; sudo reboot
# Manually run using $ sudo python raspitherm.py
#
# NOTICE: This is designed for a 320x240 screen only!
#
# Version 0.5 2017.11.26 - initial release
#         0.7 2017.12.01 - added touch screen snapshots (via workaround) 
#         0.8 2017.12.02 - expanded camera screen added data 
#	  0.8.1 - minor update to screen data format
#
# License: GPLv3, see: www.gnu.org/licenses/gpl-3.0.html
#

#from Adafruit_AMG88xx import Adafruit_AMG88xx
import adafruit_amg88xx, board, busio
import pygame
import os
import math
import sys
import time, datetime
import logging
import subprocess
import numpy as np
import RPi.GPIO as GPIO

from scipy.interpolate import griddata
from pygame.locals import *
from colour import Color

pygame.init()

# MY IMPORTS
from picamera import PiCamera
from PIL import Image, ImageDraw

CAMERA = PiCamera()
CAMERA.rotation = 180
CAMERA_DISPLAYING = False


##### VARIABLES
DEBUG	= 0	# Debug 0/1 off/on (writes to debug.log)

# INITIAL TEMPERATURE VALUES
MINTEMP = 26	# Low temp range (blue)
MAXTEMP = 32	# High temp range (red)

COLORDEPTH = 1024	
MARGIN = 20

# GPIO BUTTONS
BTN1	= 17	# Top	
BTN2	= 22	# Second
BTN3	= 23	# Third
BTN4	= 27	# Fourth

# FULL SCREEN COLORS
WHITE = (255,255,255)
BLACK = (0,0,0)
BLUE  = (0,0,255)
YELLOW= (255,255,0)
CYAN  = (0,255,255)
RED   = (255,0,0)
GRAY  = (128,128,128)

F_WIDTH  = 320*2
F_HEIGHT = 240*2
PIXEL_WIDTH = F_WIDTH / 32
PIXEL_HEIGHT = F_HEIGHT / 24
OVERLAY_ALPHA = 70

###### FUNCTIONS
def constrain(val, min_val, max_val):
    return min(max_val, max(min_val, val))

def map(x, in_min, in_max, out_min, out_max):
    return (x - in_min) * (out_max - out_min) / (in_max - in_min) + out_min

# Clear Screen
def cleartft(scolor):
    logger.info('cleartft('+str(scolor)+')')
    lcd = pygame.display.set_mode((F_WIDTH, F_HEIGHT))
    lcd.fill(scolor)
    pygame.display.update()

# Display the Mode Screen (Designed for 320x240 screen)
def displayMode():
    logger.info('displayMode()')
    cleartft(BLACK)
    lcd = pygame.display.set_mode((F_WIDTH, F_HEIGHT))
    # Title Screen
    fnt = pygame.font.Font(None, 40*2)
    txt = fnt.render('PiEyeR Camera',True,CYAN)
    lcd.blit(txt, (10*2,10*2))
    pygame.draw.lines(lcd,WHITE,False, [(10*2,50*2),(210*2,50*2)])
    # Info Box
    pygame.draw.rect(lcd,BLUE,[(10*2,60*2),(200*2,180*2)])
    pygame.draw.rect(lcd,WHITE,[(10*2,60*2),(200*2,180*2)],1)
    fnt = pygame.font.Font(None, 15*2)
    txt = fnt.render('AMG8833 Grid-Eye Thermal Camera',True,YELLOW)
    lcd.blit(txt, (20*2,70*2))
    txt = fnt.render('for Raspberry Pi',True,WHITE)
    lcd.blit(txt, (60*2,90*2))
    txt = fnt.render('PWR   = Shutdown/Startup',True,CYAN)
    lcd.blit(txt, (30*2,130*2))
    txt = fnt.render('UP/DN = Change Sensitivity',True,CYAN)
    lcd.blit(txt, (30*2,150*2))
    txt = fnt.render('CAM    = Camera Mode',True,CYAN)
    lcd.blit(txt, (30*2,170*2))
    txt = fnt.render('Touch Screen for Snapshot',True,WHITE)
    lcd.blit(txt, (30*2,190*2))
    # Function Buttons
    font_big = pygame.font.Font(None, 25*2)
    # The UP/DOWN text can be updated for supporting future features
    # They are separate from the camera sensitivity buttons.
    #mode_buttons = {'Power ->':(270,40),'Future->':(270,100),'Future->':(270,160),'Camera->':(270,220)}
    mode_buttons = {'PWR ->':(280*2,40*2), 'CAM ->':(280*2,100*2), 'FLIR->':(280*2,160*2), 'OVERLAY->':(260*2,220*2)}
    for k,v in mode_buttons.items():
        text_surface = font_big.render('%s'%k, True, YELLOW)
        rect = text_surface.get_rect(center=v)
        lcd.blit(text_surface, rect)
    pygame.display.update()

# TouchScreen - using pygame (current not working)
# Checks for screen touch
# commented out
'''
def touch():
    logger.info('touch()')
    for event in pygame.event.get():
        if(event.type is MOUSEBUTTONDOWN):
	    pos = pygame.mouse.get_pos()
            logger.info('mousedown')
	    time.sleep(0.1)
        elif(event.type is MOUSEBUTTONUP):
	    pos = pygame.mouse.get_pos()
            logger.info('mouseup')
	    screensnap()
	    break
''' and None

# TouchScreen - using tslib and custom pgm (workaround)
# due to bug in SDL lib with using pygame.
# Checks for screen touch
def touch():
    logger.info('touch() -- removed. No library tslib in Raspbian Buster.')
#    xy = subprocess.check_output(["ts_check"])
#    if(xy):
#        logger.info('screen touched'+str(xy))
#        screensnap()
    
# Screen snapshot 
# Snapshots go into snapshot subdirectory
# (Future: add transfer mechanism)
def screensnap():
    logger.info('screensnap()')
    cur_date = datetime.datetime.now().strftime('%Y%m%d%H%M%S') 
    filename="/home/pi/snapshot/"+cur_date+".png"
    subprocess.call(["sudo","fbgrab","-d","/dev/fb1",filename])
    time.sleep(0.2)
    lcd = pygame.display.set_mode((F_WIDTH, F_HEIGHT))
    lcd.fill(WHITE)
    pygame.display.update()
    time.sleep(0.2)
    lcd.fill(BLUE)
    pygame.display.update()
    time.sleep(0.2)

# TODO FUTURE FEATURES
def future(msg):
    logger.info('future('+msg+')')
    cleartft(BLUE)
    lcd = pygame.display.set_mode((F_WIDTH, F_HEIGHT))
    font_big = pygame.font.Font(None, 50)
    text_surface = font_big.render('FUTURE', True, WHITE)
    rect = text_surface.get_rect(center=(160,120))
    lcd.blit(text_surface, rect)
    pygame.display.update()
    time.sleep(2)

# IR Thermal Camera
def ir_camera():
    logger.info('ir_camera()')
    lcd = pygame.display.set_mode((F_WIDTH, F_HEIGHT))
    lcd.fill(BLUE)
    pygame.display.update()
    time.sleep(0.5)
    showBtns = 0
    offset = 15 #was zero - works better this way with new adafruit library.
    loop = 1
    while (loop):
        # read the pixels
 #        pixels_d = sensor.readPixels()
        pixels_d = []
        for row in sensor.pixels:
            pixels_d = pixels_d + row
        # Remap pixels
        pixels_d = [map(p, MINTEMP+offset, MAXTEMP+offset, 0, COLORDEPTH - 1) for p in pixels_d]
        #Perform interpolation
        bicubic = griddata(points, pixels, (grid_x, grid_y), method='cubic')
        #Draw Image
        for ix, row in enumerate(bicubic):
                for jx, pixel in enumerate(row):
                    pygame.draw.rect(lcd, colors[constrain(int(pixel), 0, COLORDEPTH- 1)], (PIXEL_HEIGHT * ix, PIXEL_WIDTH * jx, PIXEL_HEIGHT, PIXEL_WIDTH))
	
        # Flip the screen horizontally to match front facing IP camera
        surf = pygame.transform.flip(lcd,True,False)
        lcd.blit(surf,(0,0))
        # Add buttons (show for X seconds)
        if (showBtns < 25):
            fnt = pygame.font.Font(None, 15*2)
            mode_buttons = {'PWR ->':(280*2,40*2), '   UP ->':(280*2,100*2), 'DOWN->':(280*2,160*2), 'MODE->':(280*2,220*2)}
            for k,v in mode_buttons.items():
                text_surface = fnt.render('%s'%k, True, GRAY)
                rect = text_surface.get_rect(center=v)
                lcd.blit(text_surface, rect)
        showBtns = showBtns + 1
        # Add Data to screen
        fnt = pygame.font.Font(None, 15*2)
        cur_date = datetime.datetime.now().strftime('%a  %d  %b %H : %M : %S %Z %Y') 
        text_surface = fnt.render(cur_date, True, GRAY)
        lcd.blit(text_surface, (10*2,220*2))
        text = "Min  = {0:.0f} C".format(min(pixels_d))
        text_surface = fnt.render(text, True, GRAY)
        lcd.blit(text_surface, (10*2,20*2))
        text = "Max = {0:.0f} C".format(max(pixels_d))
        text_surface = fnt.render(text, True, GRAY)
        lcd.blit(text_surface, (10*2,30*2))
        pygame.display.update()
        # GPIO Button Press 
        if GPIO.input(BTN4) == GPIO.LOW:
            logger.info("stopping ir_camera()")
            loop = 0
            time.sleep(0.5)	
        if GPIO.input(BTN2) == GPIO.LOW:
            logger.info("UP")
            offset = offset - 1
            showBtns = 0
            time.sleep(0.5)	
        if GPIO.input(BTN3) == GPIO.LOW:
            logger.info("DOWN")
            offset = offset + 1
            showBtns = 0
            time.sleep(0.5)	
        # Touch Screen Snapshot
        #touch()


def camera(cam_displaying):
	if cam_displaying:
		CAMERA.stop_preview()
		CAMERA.close()
		return False
	else:
		CAMERA = PiCamera()
		CAMERA.rotation = 180
		CAMERA_DISPLAYING = false
		CAMERA.start_preview()
		return True


def overlay():
    CAMERA = PiCamera()
    CAMERA.rotation = 180
    CAMERA.start_preview()
    sensitivity = -7 #BT edit: was -5
    overlay1, overlay2 = None, None
    loop = True
    startT = time.time()
    while loop:
        endT = time.time()
        if (endT - startT > 3600):
            print('restarting overlay...')
            logger.info('restarting overlay...')
            startT = time.time()
            loop = False

        pad = Image.new('RGB', (F_WIDTH,F_HEIGHT))
        draw = ImageDraw.Draw(pad)

        #read the pixels
#        pixels_d = sensor.readPixels()
        pixels_d = []
        for row in sensor.pixels:
            pixels_d = pixels_d + row
        # Remap pixels
        # Remap pixels
        pixels = [map(p, MINTEMP+sensitivity, MAXTEMP+sensitivity, 0, COLORDEPTH - 1) for p in pixels_d]
        #Perform interpolation
        bicubic = griddata(points, pixels, (grid_x, grid_y), method='cubic')

        #Draw Overlay
        x = 31 * PIXEL_WIDTH
        y = -6 * PIXEL_HEIGHT
        for ix, row in enumerate(bicubic):
            for jx, pixel in enumerate(row):
                draw.rectangle((
                    x, y, x + PIXEL_WIDTH, y + PIXEL_HEIGHT),
                    fill = colors[constrain(int(pixel), 0, COLORDEPTH- 1)])
                y = y + PIXEL_HEIGHT
            x = x - PIXEL_WIDTH
            y = -6 * PIXEL_HEIGHT

        if overlay1 == None:
            overlay1 = CAMERA.add_overlay(pad.tobytes(), size=pad.size, layer=3, alpha=OVERLAY_ALPHA)
            if not overlay2 == None:
                CAMERA.remove_overlay(overlay2)
                overlay2 = None
        else:
            overlay2 = CAMERA.add_overlay(pad.tobytes(), size=pad.size, layer=3, alpha=OVERLAY_ALPHA)
            if not overlay1 == None:
                CAMERA.remove_overlay(overlay1)
                overlay1 = None

        if GPIO.input(BTN2) == GPIO.LOW:
            sensitivity = sensitivity - 1
            time.sleep(0.5)
        elif GPIO.input(BTN3) == GPIO.LOW:
            sensitivity = sensitivity + 1
            time.sleep(0.5)
        elif GPIO.input(BTN4) == GPIO.LOW:
            loop = False
            time.sleep(0.5)

    if not overlay1 == None:
        CAMERA.remove_overlay(overlay1)
    if not overlay2 == None:
        CAMERA.remove_overlay(overlay2)
    CAMERA.stop_preview()
    CAMERA.close()


######
# MAIN
######
# Setup Logging
logger = logging.getLogger()
handler = logging.FileHandler('debug.log')
if DEBUG:
    logger.setLevel(logging.INFO)
    handler.setLevel(logging.INFO)
else:
    logger.setLevel(logging.ERROR)
    handler.setLevel(logging.ERROR)
log_format = '%(asctime)-6s: %(name)s - %(levelname)s - %(message)s'
handler.setFormatter(logging.Formatter(log_format))
logger.addHandler(handler)

logger.info('Starting')

# Setup OS Env
os.putenv('SDL_VIDEODRIVER', 'fbcon')
os.putenv('SDL_FBDEV', '/dev/fb1')
os.putenv('SDL_MOUSEDRV', 'TSLIB')
os.putenv('SDL_MOUSEDEV', '/dev/input/touchscreen')


# Setup GPIO buttons
GPIO.setmode(GPIO.BCM)
GPIO.setup(BTN1, GPIO.IN, pull_up_down=GPIO.PUD_UP)
GPIO.setup(BTN2, GPIO.IN, pull_up_down=GPIO.PUD_UP)
GPIO.setup(BTN3, GPIO.IN, pull_up_down=GPIO.PUD_UP)
GPIO.setup(BTN4, GPIO.IN, pull_up_down=GPIO.PUD_UP)

## Thermal Sensor
#sensor = Adafruit_AMG88xx()
i2c = busio.I2C(board.SCL, board.SDA)
sensor = adafruit_amg88xx.AMG88XX(i2c)
points = [(math.floor(ix / 8), (ix % 8)) for ix in range(0, 64)]
grid_x, grid_y = np.mgrid[0:7:32j, 0:7:32j]

# Set Color range
blue = Color("indigo")
colors = list(blue.range_to(Color("red"), COLORDEPTH))

# Create the array of colors
colors = [(int(c.red * 255), int(c.green * 255), int(c.blue * 255)) for c in colors]


# PYGAME SCREEN
#pygame.init() # initialized earlier
pygame.mouse.set_visible(False)
cleartft(BLACK)

logger.info('setup complete')

# Display MODE screen
displayMode()

# Wait for sensor initialize
time.sleep(.1)

# BT edit: Run this upon start after 15secs of menu screen
#          if user presses "mode," it will go back to menu screen
CAMERA.close()
CAMERA_DISPLAYING = False
startT = time.time()
overlayRun = 0
while True:
        if (overlayRun == 12):
                print('quitting after 12 overlays...')
                logger.info('quitting after 12 overlays...')
                cleartft(BLACK)
                time.sleep(5)
                sys.exit(1)

        endT = time.time() #BT edit: if no button pressed in 1min, start overlay
        if (endT - startT > 60):
                overlayRun = overlayRun + 1
                print('entering overlay by default...')
                logger.info('entering overlay by default')
                overlay()
                displayMode()
                startT = time.time()
                time.sleep(.5)

        # GPIO Button Press to exit
        if GPIO.input(BTN1) == GPIO.LOW:
            cleartft(BLACK)
            time.sleep(5)
            sys.exit(0)

        if GPIO.input(BTN2) == GPIO.LOW:
        # CAMERA
            if not CAMERA_DISPLAYING:
                CAMERA = PiCamera()
                CAMERA.rotation = 180
                CAMERA.start_preview()
                CAMERA_DISPLAYING = True
                #displayMode()
                time.sleep(0.5)

        if GPIO.input(BTN3) == GPIO.LOW:
        # IR_CAMERA
            cleartft(BLACK)
            time.sleep(0.1)
            ir_camera()
            displayMode()
            time.sleep(0.5)

        if GPIO.input(BTN4) == GPIO.LOW:
            if CAMERA_DISPLAYING:
                CAMERA.stop_preview()
                CAMERA_DISPLAYING = False
                CAMERA.close()
            else:
                # OVERLAY
                overlay()
                displayMode()
                time.sleep(0.5)

        time.sleep(.1)

### END

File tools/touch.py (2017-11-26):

#!/usr/bin/python
#
# Test Touch Screen controls
#
# Usage:  
# $ sudo python touch.py


import pygame
from pygame.locals import *
import os
from time import sleep
import RPi.GPIO as GPIO
 
print "NOTICE: PyGame SDL1.x Library DOES NOT WORK WITH TOUCH"

#Setup the GPIOs as outputs - only 23 and 27 are available
GPIO.setmode(GPIO.BCM)
GPIO.setup(23, GPIO.OUT)
GPIO.setup(27, GPIO.OUT)
 
#Colours
WHITE = (255,255,255)
 
os.putenv('SDL_VIDEODRIVER', 'fbcon')
os.putenv('SDL_FBDEV', '/dev/fb1')
os.putenv('SDL_MOUSEDRV', 'TSLIB')
os.putenv('SDL_MOUSEDEV', '/dev/input/touchscreen')
 
pygame.init()
pygame.mouse.set_visible(False)
lcd = pygame.display.set_mode((320, 240))
lcd.fill((0,0,0))
pygame.display.update()
 
font_big = pygame.font.Font(None, 50)
 
touch_buttons = {'27 on':(80,60), '23 on':(240,60), '27 off':(80,180), '23 off':(240,180)}
 
for k,v in touch_buttons.items():
    text_surface = font_big.render('%s'%k, True, WHITE)
    rect = text_surface.get_rect(center=v)
    lcd.blit(text_surface, rect)
 
pygame.display.update()
 
while True:
    # Scan touchscreen events
    for event in pygame.event.get():
        if(event.type is MOUSEBUTTONDOWN):
            pos = pygame.mouse.get_pos()
            print pos
        elif(event.type is MOUSEBUTTONUP):
            pos = pygame.mouse.get_pos()
            print pos
            #Find which quarter of the screen we're in
            x,y = pos
            if y < 120:
                if x < 160:
                    GPIO.output(27, False)
                else:
                    GPIO.output(23, False)
            else:
                if x < 160:
                    GPIO.output(27, True)
                else:
                    GPIO.output(23, True)
    sleep(0.1)

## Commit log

2017-11-30 Added STL 3d files
    [PiEyeR Body.stl, PiEyeR CamBackPlate.stl, PiEyeR Front.stl]
2017-12-11 Updates for Raspi Zero
    [PiEyeR Body.stl, PiEyeR CamBackPlate.stl, PiEyeR Front.stl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]
2019-02-27 fix tabs to spaces
    [raspitherm.py]
2019-08-15 fix tab indent for camera()
    [raspitherm.py]
